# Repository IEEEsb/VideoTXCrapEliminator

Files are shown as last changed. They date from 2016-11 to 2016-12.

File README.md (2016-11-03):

## Design
This device is designed to hopefully eliminate startup crap spewed by low-cost FPV video transmitters while their PLL isn't locked yet, sweeping through the whole TX band and interfering anyone nearby. 
What this does is switching the VTX output to a load during VTX startup and then, after a configurable amount of time, switch the VTX output back to the antenna. 
The key aspects of the design are getting a high enough isolation when the antenna is disconnected, being capable of eating the VTX output while it's switched to the load and not generating extra harmonics or distortion that could potentially interfere regulated bands.

This design is based on a Peregrine Semiconductor PE42423 6GHz absorprive RF switch, capable of eating +26 dBm into its embedded terminators and letting about 2W through with very good linearity specs.
It was selected because of previous satisfactory experience with Peregrine Semiconductors and because of the inherent robustness of their UltraCMOS technology compared to GaAs devices. Also, it's cheap and promises an isolation of 40 dB at 6 GHz which should be enough.

The RF path consists of the switch itself, an AC coupling capacitor for the antenna input (the video TX shoudn't output DC but just in case...), a 50 ohm termination load for the unused switch branch
and a 1M resistor (should be around 100k to 1M) to give a path for the DC bias current of the switches. Peregrine says that you can go without AC coupling caps if all switch IO's are kept at 0V DC, and someone from Peregrine
support told me that it was a good practice to add these bias resistors and where to add them. Reality agrees.

There's a PIC microcontroller to time and control the switch. Basically, supervisors/POR generator IC's were just as expensive as the PIC and this way you can program your delay time.

A 24V input capable and reverse polarity protected voltage regulator provides the 3.3V required by the switch and the PIC. As both devices consume about 400uA there are 1K resistors in series to act as power filter combined with the decoupling capacitors. Voltage drop across them is negligible.

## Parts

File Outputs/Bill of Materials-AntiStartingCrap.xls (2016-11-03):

Comment | Description | Designator | Footprint | LibRef | Quantity
100 nF | CAP CER 0.1UF 25V X7R 0603 | C1, C4 | CAPC1608X10L | CL10B104KA8NNNC | 2
22 pF | CAP CER 22PF 50V NP0 0603 | C2, C6 | CAPC1608X10L | GCM1885C1H220JA16D | 2
10 nF | CAP CER 10000PF 50V NP0 0603 | C3 | CAPC1608X10L | GRM1885C1H103JA01D | 1
2.2 uF | CAP CER 2.2UF 25V X5R 0603 | C5, C7 | CAPC1608X10L | GRM188R61E225MA12D | 2
BAT54SLT1G | Schottky Diodes & Rectifiers 30V 225mW Dual | D1 | SOT95P237X111-3N | BAT54SLT1G | 1
RPSMA_MACHO_CHINO |  | J1 | SMACHINO | RPSMA_MACHO_CHINO | 1
RPSMA_HEMBRA_CHINO |  | J2 | SMACHINO | RPSMA_HEMBRA_CHINO | 1
1 k | Thick Film Resistors - SMD 1/10watt 1.0Kohms 1% | R1, R3, R7 | RESC1608X05N | CRCW06031K00FKEA | 3
1 M | Thick Film Resistors - SMD 1/10watt 1.0Mohms 1% | R2, R6 | RESC1608X05N | CRCW06031M00FKEA | 2
49.9 | RES SMD 49.9 OHM 1% 1/10W 0603 | R4 | RESC1608X05N | CRCW060349R9FKEA | 1
PIC10F200T-I/OT | IC MCU 8BIT 384B FLASH SOT23-6 | U1 | SOT95P270X145-6N | PIC10F200T-I/OT | 1
PE42423MLBA-Z | IC RF SWITCH SPDT 50 OHM 16QFN | U2 | QFN50P300X300X90_HS-17N _PEREGRINE | PE42423MLBA-Z | 1
AP2204K-3.3TRG1 | IC REG LDO 3.3V 0.15A SOT25 | U3 | SOT95P270X145-5N | AP2204K-3.3TRG1 | 1

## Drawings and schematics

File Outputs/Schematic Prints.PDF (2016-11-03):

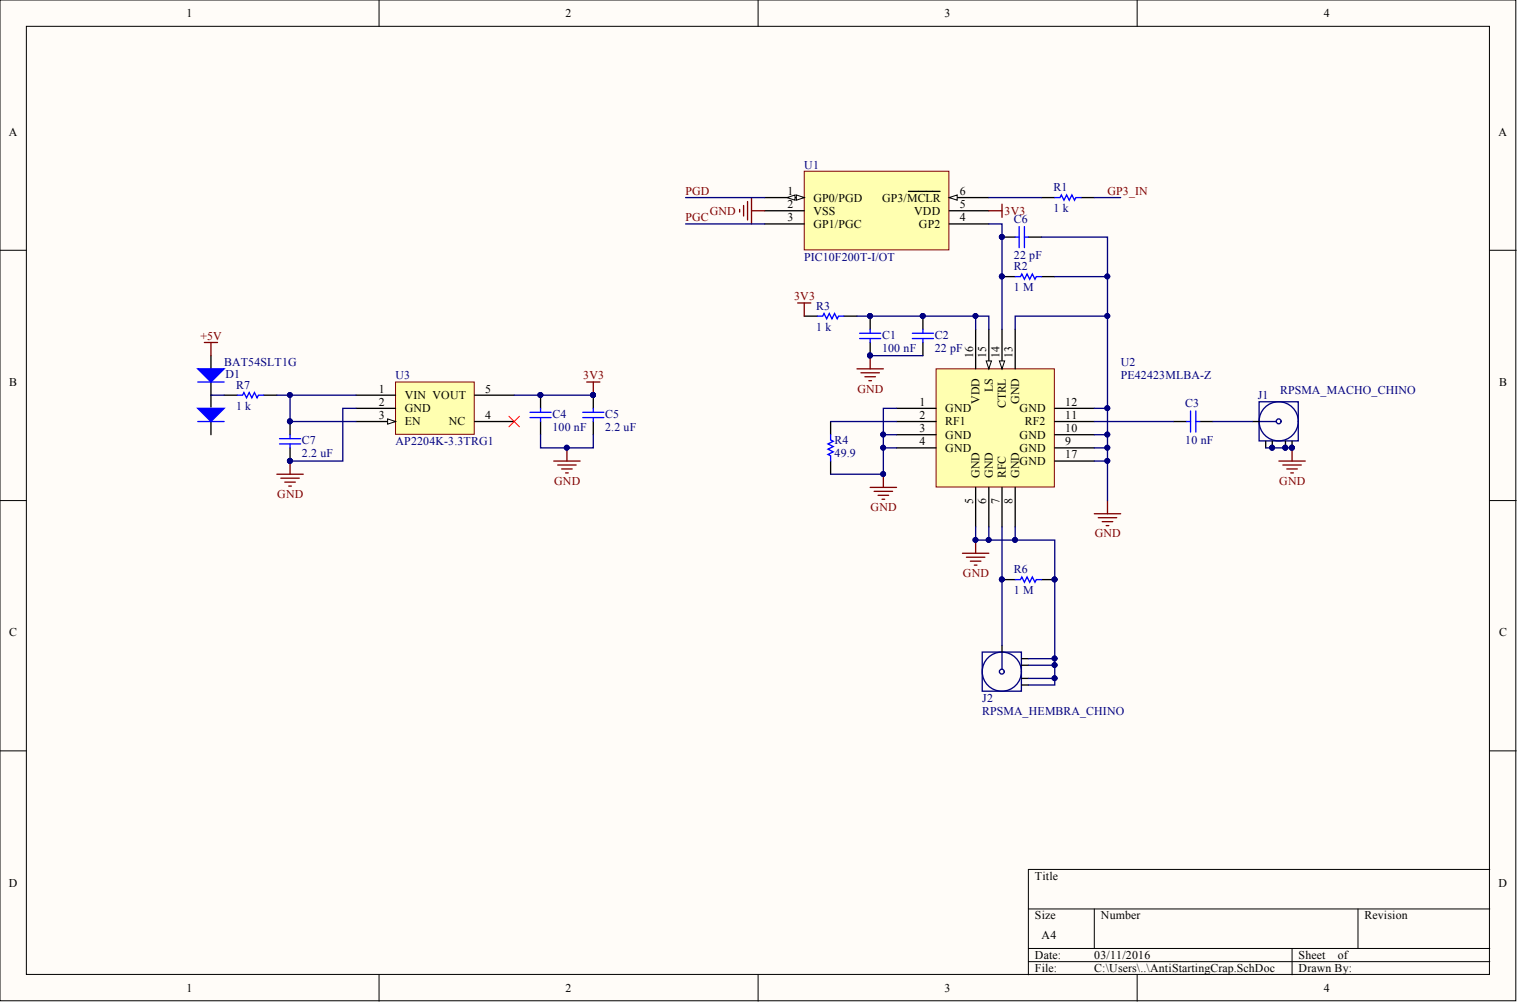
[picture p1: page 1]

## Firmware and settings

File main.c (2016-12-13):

// PIC10F200 Configuration Bit Settings

// 'C' source line config statements

// CONFIG
#pragma config WDTE = OFF       // Watchdog Timer (WDT disabled)
#pragma config CP = OFF         // Code Protect (Code protection off)
#pragma config MCLRE = OFF      // Master Clear Enable (GP3/MCLR pin fuction is digital I/O, MCLR internally tied to VDD)
#define _XTAL_FREQ 4000000
// #pragma config statements should precede project file includes.
// Use project enums instead of #define for ON and OFF.

#include <xc.h>

void main(void) {
    OPTION = 0;
    TRISGPIO = 0b00011011;
    GPIObits.GP2 = 0;
    __delay_ms(3000);
    GPIObits.GP2 = 1;
    while (1) {
        __delay_ms(200);
        GPIObits.GP2 = GPIObits.GP3 ? 1 : 0;
    }
    return;
}
